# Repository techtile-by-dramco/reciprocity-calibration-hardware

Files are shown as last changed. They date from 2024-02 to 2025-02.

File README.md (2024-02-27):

# Techtile PLL board ✅

This PCB was developed by Guus Leenders from KU Leuven, in collaboration with DRAMCO, with assistance from Jarne Van Mulders. The board is utilized in a distributed antenna or **Radioweave** infrastructure and delivers a phase-synchronous RF output to the USRP by means of a PPS and 10MHz signal. 

❗❗ This board is specifically designed for the **USRP B210** by Ettus. ❗❗

The PPS and 10MHz signals (coming from the octoclocks CDA2990) are amplified using on board buffers and are connected to the
* PLL IC (MAX287x) ❗❗ **--> allowing for ∿ phase synchronisation ∿**
* the flat cable connector (given that the raspberry pi also has access to these signals) ❗
* the input SMA connectors of the USRPs intself ❗❗
  * ** 10 MHz --> ∿ frequency synchronisation ∿ for internal (RF) PLLs**
  * ** PPS --> ⏰ time synchronisation ⏰**

The board is controlled via I2C commands and features a flat cable input connected to the RPI HAT (developed by DRAMCO) to drive the PLL output. The most important registers are displayed below.

###  PLL board general settings ⚙️

|Register name| byte |
|--|--|
|REGISTER_SETTINGS_DEVICE_ID | 0x00 |
|REGISTER_SETTINGS_HARDWARE_VERSION | 0x01 |
|REGISTER_SETTINGS_FIRMWARE_VERSION | 0x02 |
|REGISTER_SETTINGS_SAVE_TO_EEPROM | 0x03 |
|REGISTER_SETTINGS_PLL_REFERENCE_CLOCK  | 0x04 |
|REGISTER_SETTINGS_PLL_REFERENCE_DIVIDER| 0x06 |
|REGISTER_SETTINGS_LED_MODE | 0x07 |
|REGISTER_SETTINGS_LED_BLINK_ON_TIME | 0x08 |
|REGISTER_SETTINGS_LED_BLINK_OFF_TIME | 0x09 |

###  PLL (MAX287x) settings ⚙️

|Register name| byte | Remarks |
|--|--|--|
|REGISTER_PLL_POWER | 0x10 | |
|REGISTER_PLL_FREQUENCY | 0x11 | 2 byte (uint16) |
|REGISTER_PLL_ENABLE_OUTPUT | 0x13 | |
|REGISTER_PLL_LOCK_DETECTED | 0x14 | Read only |
|REGISTER_PLL_MODE | 0x15 | Read only |

# Phase synchronisation in Techtile ToDo 📝
- Work further on python script to achieve phase-synchronised outputs with the B210 USRP. Validate and visualize the signals on the oscilloscope by using two separate setups consisting of RPI, USRP, PLL, PPS, and 10 MHz input.
- Current status ⏳ PENDING ⏳

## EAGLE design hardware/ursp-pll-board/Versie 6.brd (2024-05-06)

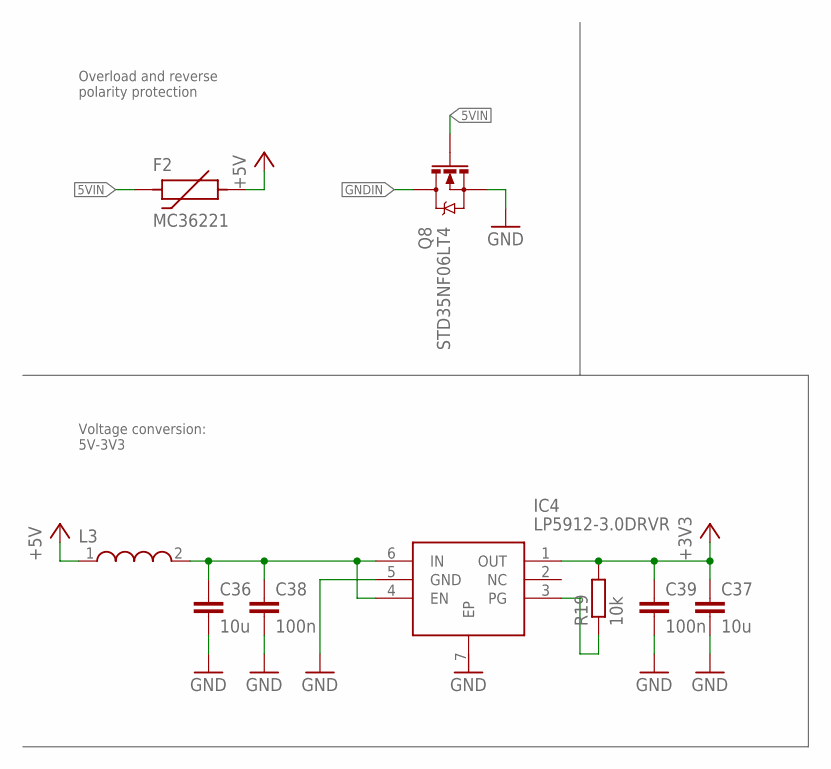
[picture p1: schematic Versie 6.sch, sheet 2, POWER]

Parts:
C36, C37: 10u; C0603
C38, C39: 100n; C0603
F2: MC36221; 1206
IC4: LP5912-3.0DRVR; SON65P200X200X80-7N
L3: WE-CBA_0603(WB/HS); WE-CBA_0603(W=2.2)
Q8: STD35NF06LT4; SOT23-3
R19: 10k; R0603

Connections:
5VIN: F2.P$1, Q8.1 (G); also elsewhere on the board
+3V3: C37.1, C39.1, IC4.1 (OUT), R19.2; also elsewhere on the board
+5V: F2.P$2, L3.1
GND: C36.2, C37.2, C38.2, C39.2, IC4.5 (GND), Q8.2 (S); also elsewhere on the board
GNDIN: Q8.3 (D); also elsewhere on the board
unnamed: C36.1, C38.1, IC4.4 (EN), IC4.6 (IN), L3.2
unnamed: IC4.3 (PG), R19.1

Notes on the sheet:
Overload and reverse polarity protection
Voltage conversion: 5V-3V3

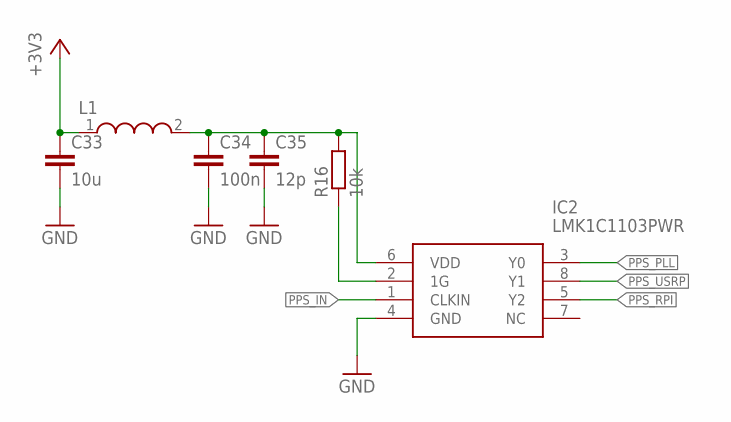
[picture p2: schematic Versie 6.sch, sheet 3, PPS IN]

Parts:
C33: 10u; C0603
C34: 100n; C0603
C35: 12p; C0603
IC2: LMK1C1103PWR; SOP65P640X120-8N
L1: WE-CBA_0603(WB/HS); WE-CBA_0603(W=2.2)
R16: 10k; R0603

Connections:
+3V3: C33.1, L1.1; also elsewhere on the board
GND: C33.2, C34.2, C35.2, IC2.4 (GND); also elsewhere on the board
unnamed: IC2.2 (1G), R16.1
unnamed: C34.1, C35.1, IC2.6 (VDD), L1.2, R16.2
PPS_IN: IC2.1 (CLKIN); also elsewhere on the board
PPS_PLL: IC2.3 (Y0); also elsewhere on the board
PPS_RPI: IC2.5 (Y2); also elsewhere on the board
PPS_USRP: IC2.8 (Y1); also elsewhere on the board

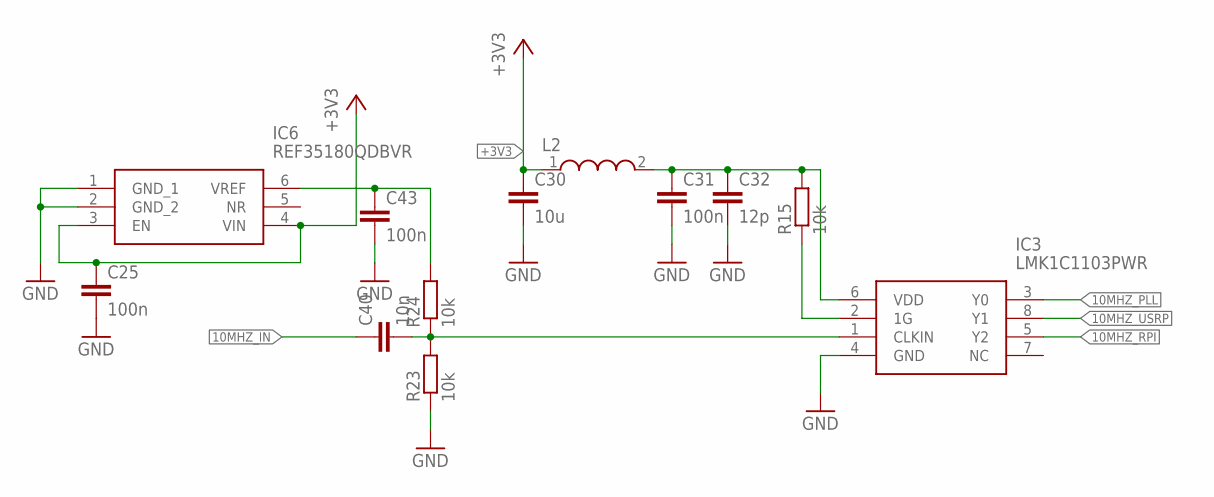
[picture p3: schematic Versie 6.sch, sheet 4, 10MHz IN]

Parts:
C25, C31, C43: 100n; C0603
C30: 10u; C0603
C32: 12p; C0603
C40: 10n; C0603
IC3: LMK1C1103PWR; SOP65P640X120-8N
IC6: REF35180QDBVR; SOT95P280X145-6N
L2: WE-CBA_0603(WB/HS); WE-CBA_0603(W=2.2)
R15, R23, R24: 10k; R0603

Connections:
10MHZ_IN: C40.1; also elsewhere on the board
10MHZ_PLL: IC3.3 (Y0); also elsewhere on the board
10MHZ_RPI: IC3.5 (Y2); also elsewhere on the board
10MHZ_USRP: IC3.8 (Y1); also elsewhere on the board
+3V3: C25.1, C30.1, IC6.3 (EN), IC6.4 (VIN), L2.1; also elsewhere on the board
GND: C25.2, C30.2, C31.2, C32.2, C43.2, IC3.4 (GND), IC6.1 (GND_1), IC6.2 (GND_2), R23.1; also elsewhere on the board
unnamed: C40.2, IC3.1 (CLKIN), R23.2, R24.1
unnamed: IC3.2 (1G), R15.1
unnamed: C31.1, C32.1, IC3.6 (VDD), L2.2, R15.2
unnamed: C43.1, IC6.6 (VREF), R24.2

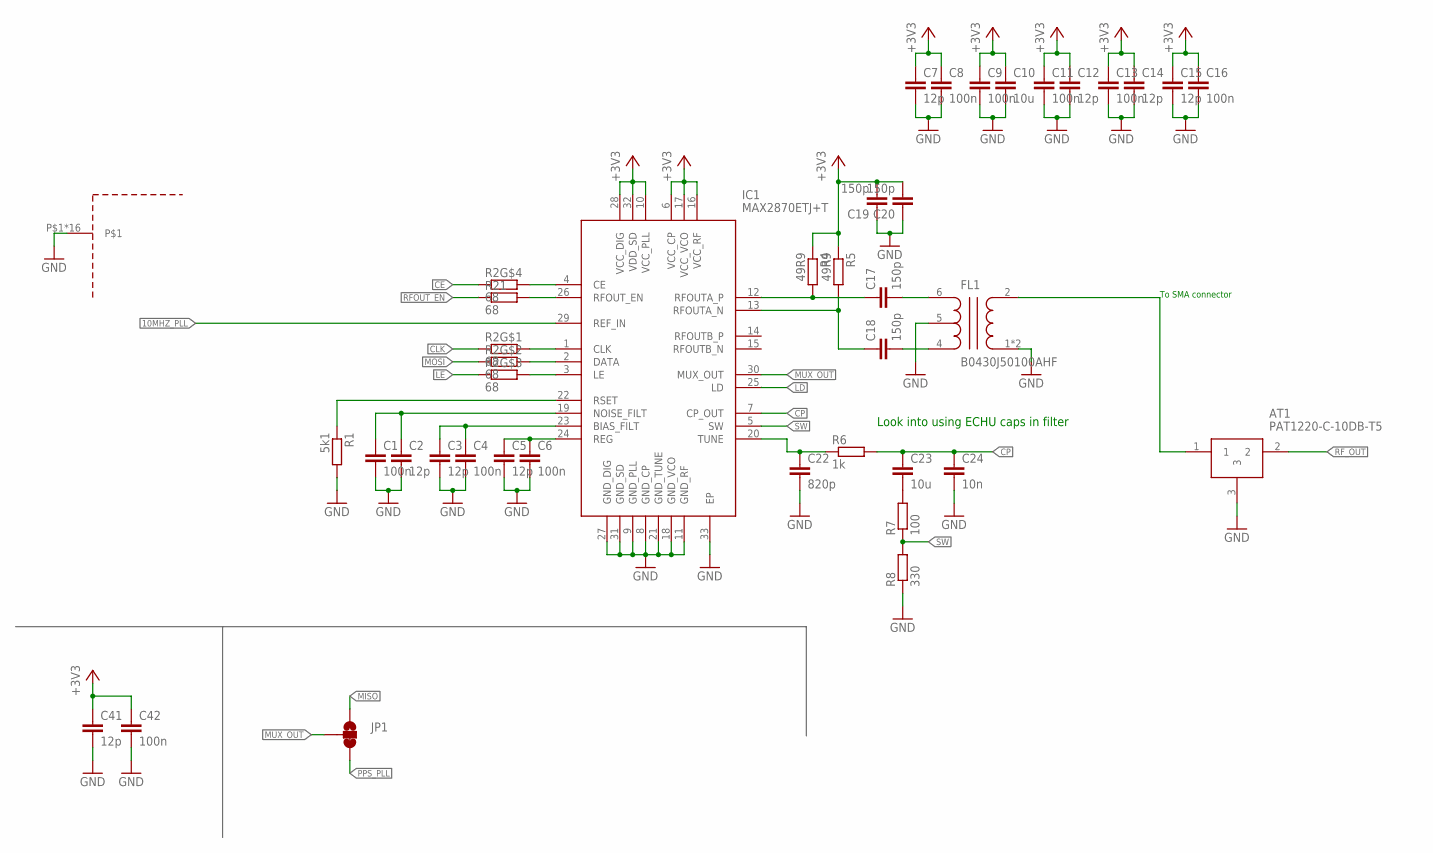
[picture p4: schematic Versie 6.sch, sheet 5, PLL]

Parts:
AT1: PAT1220-C-10DB-T5; PAT1220C10DBT5
C1, C4, C6, C8, C9, C11, C13, C16, C42: 100n; C0603
C2, C3, C5, C7, C12, C14, C15, C41: 12p; C0603
C10, C23: 10u; C0603
C17, C18, C19, C20: 150p; C0402
C22: 820p; C0603
C24: 10n; C0603
FL1: B0430J50100AHF
IC1: MAX2870ETJ+T; QFN50P500X500X80-33N
JP1: JUMPER-SMT_3_1-NC_TRACE_SILK; SMT-JUMPER_3_1-NC_TRACE_SILK
R1: 5k1; R0603
R2: 68; CAY16A1003F4LF
R4, R5: 49R9; R0402
R6: 1k; R0603
R7: 100; R0603
R8: 330; R0603
R21: 68; R0603
U$1: BMI-S-209-F-20-R

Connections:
10MHZ_PLL: IC1.29 (REF_IN); also elsewhere on the board
+3V3: C7.1, C8.1, C9.1, C10.1, C11.1, C12.1, C13.1, C14.1, C15.1, C16.1, C19.2, C20.2, C41.1, C42.1, IC1.6 (VCC_CP), IC1.10 (VCC_PLL), IC1.16 (VCC_RF), IC1.17 (VCC_VCO), IC1.28 (VCC_DIG), IC1.32 (VDD_SD), R4.1, R5.1; also elsewhere on the board
CE: R2.4 (1); also elsewhere on the board
CLK: R2.1; also elsewhere on the board
CP: C23.1, C24.1, IC1.7 (CP_OUT), R6.2
GND: AT1.3, C1.2, C2.2, C3.2, C4.2, C5.2, C6.2, C7.2, C8.2, C9.2, C10.2, C11.2, C12.2, C13.2, C14.2, C15.2, C16.2, C19.1, C20.1, C22.2, C24.2, C41.2, C42.2, FL1.1 (GND_1), FL1.3 (GND_1), FL1.5 (NC), IC1.8 (GND_CP), IC1.9 (GND_PLL), IC1.11 (GND_RF), IC1.18 (GND_VCO), IC1.21 (GND_TUNE), IC1.27 (GND_DIG), IC1.31 (GND_SD), IC1.33 (EP), R1.2, R8.1, U$1.P$1, U$1.P$2, U$1.P$3, U$1.P$4, U$1.P$5, U$1.P$6, U$1.P$7, U$1.P$8, U$1.P$9, U$1.P$10, U$1.P$11, U$1.P$12, U$1.P$13, U$1.P$14, U$1.P$15, U$1.P$16; also elsewhere on the board
LD: IC1.25 (LD); also elsewhere on the board
LE: R2.3 (1); also elsewhere on the board
MISO: JP1.1; also elsewhere on the board
MOSI: R2.2 (1); also elsewhere on the board
MUX_OUT: IC1.30 (MUX_OUT), JP1.2
unnamed: C5.1, C6.1, IC1.24 (REG)
unnamed: IC1.22 (RSET), R1.1
unnamed: IC1.1 (CLK), R2.8 (2)
unnamed: IC1.2 (DATA), R2.7 (2)
unnamed: IC1.3 (LE), R2.6 (2)
unnamed: C1.1, C2.1, IC1.19 (NOISE_FILT)
unnamed: C3.1, C4.1, IC1.23 (BIAS_FILT)
unnamed: IC1.26 (RFOUT_EN), R21.2
unnamed: IC1.4 (CE), R2.5 (2)
unnamed: C22.1, IC1.20 (TUNE), R6.1
unnamed: C17.1, IC1.12 (RFOUTA_P), R4.2
unnamed: C18.1, IC1.13 (RFOUTA_N), R5.2
unnamed: C18.2, FL1.4 (BALANCED_PORT_1)
unnamed: C17.2, FL1.6 (BALANCED_PORT_2)
unnamed: C23.2, R7.2
unnamed: AT1.1, FL1.2 (UNBALANCED)
PPS_PLL: JP1.3; also elsewhere on the board
RFOUT_EN: R21.1; also elsewhere on the board
RF_OUT: AT1.2; also elsewhere on the board
SW: IC1.5 (SW), R7.1, R8.2

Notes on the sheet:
To SMA connector
Look into using ECHU caps in filter

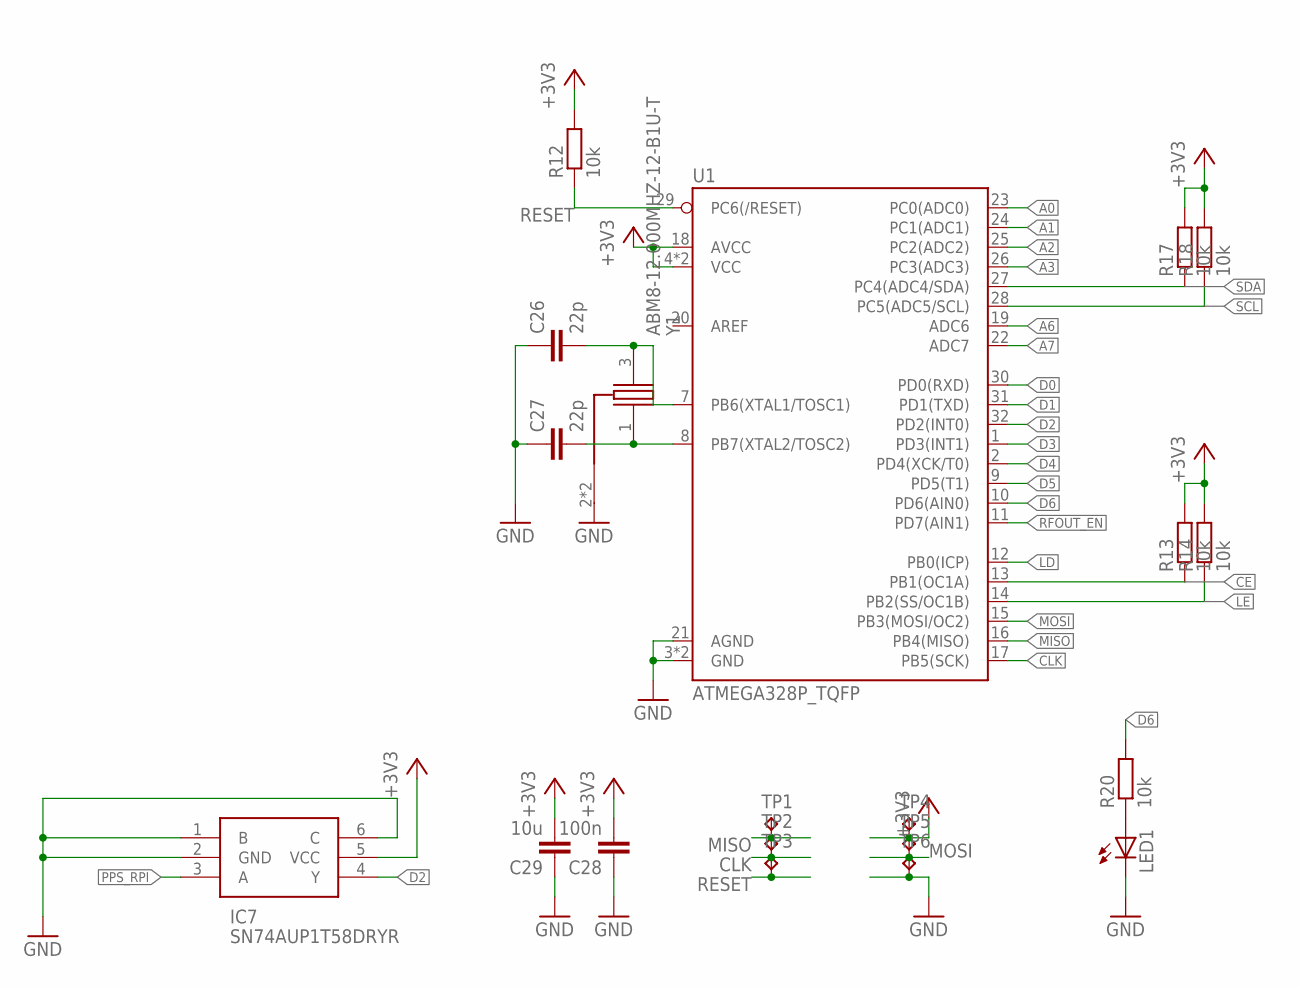
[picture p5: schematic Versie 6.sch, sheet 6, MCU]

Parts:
C26, C27: 22p; C0603
C28: 100n; C0603
C29: 10u; C0603
IC7: SN74AUP1T58DRYR; SON50P100X145X60-6N
LED1: LEDCHIPLED_0805; CHIPLED_0805
R12, R13, R14, R17, R18, R20: 10k; R0603
TP1, TP2, TP3, TP4, TP5, TP6: TPTP16R; TP16R
U1: ATMEGA328P_TQFP; TQFP32-08
Y1: ABM8-12.000MHZ-12-B1U-T; ABM810000MHZ12D2W

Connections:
+3V3: C28.2, C29.2, IC7.5 (VCC), R12.2, R13.2, R14.2, R17.2, R18.2, TP4.TP, U1.4 (VCC), U1.6 (VCC), U1.18 (AVCC); also elsewhere on the board
A0: U1.23 (PC0(ADC0)); also elsewhere on the board
A1: U1.24 (PC1(ADC1)); also elsewhere on the board
A2: U1.25 (PC2(ADC2)); also elsewhere on the board
A3: U1.26 (PC3(ADC3)); also elsewhere on the board
A6: U1.19 (ADC6)
A7: U1.22 (ADC7)
CE: R13.1, U1.13 (PB1(OC1A)); also elsewhere on the board
CLK: TP2.TP, U1.17 (PB5(SCK)); also elsewhere on the board
D0: U1.30 (PD0(RXD)); also elsewhere on the board
D1: U1.31 (PD1(TXD)); also elsewhere on the board
D2: IC7.4 (Y), U1.32 (PD2(INT0))
D3: U1.1 (PD3(INT1)); also elsewhere on the board
D4: U1.2 (PD4(XCK/T0)); also elsewhere on the board
D5: U1.9 (PD5(T1))
D6: R20.2, U1.10 (PD6(AIN0))
GND: C26.1, C27.1, C28.1, C29.1, IC7.1 (B), IC7.2 (GND), IC7.6 (C), LED1.C, TP6.TP, U1.3 (GND), U1.5 (GND), U1.21 (AGND), Y1.2 (GND_1), Y1.4 (GND_1); also elsewhere on the board
LD: U1.12 (PB0(ICP)); also elsewhere on the board
LE: R14.1, U1.14 (PB2(SS/OC1B)); also elsewhere on the board
MISO: TP1.TP, U1.16 (PB4(MISO)); also elsewhere on the board
MOSI: TP5.TP, U1.15 (PB3(MOSI/OC2)); also elsewhere on the board
unnamed: LED1.A, R20.1
unnamed: C26.2, U1.7 (PB6(XTAL1/TOSC1)), Y1.3 (X2)
unnamed: C27.2, U1.8 (PB7(XTAL2/TOSC2)), Y1.1 (X1)
PPS_RPI: IC7.3 (A); also elsewhere on the board
RESET: R12.1, TP3.TP, U1.29 (PC6(/RESET))
RFOUT_EN: U1.11 (PD7(AIN1)); also elsewhere on the board
SCL: R18.1, U1.28 (PC5(ADC5/SCL)); also elsewhere on the board
SDA: R17.1, U1.27 (PC4(ADC4/SDA)); also elsewhere on the board

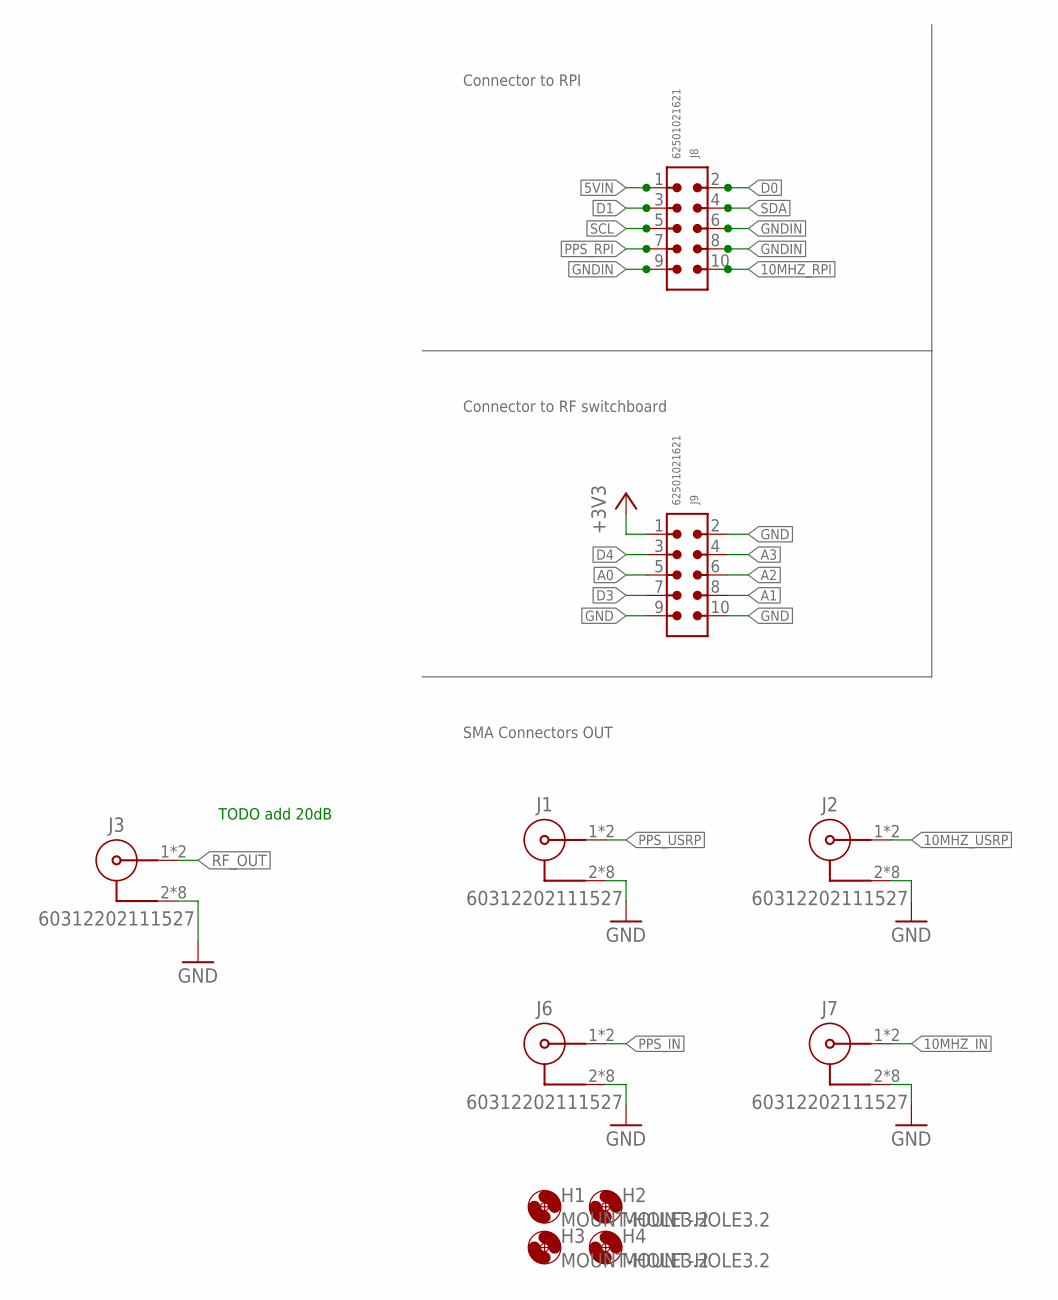
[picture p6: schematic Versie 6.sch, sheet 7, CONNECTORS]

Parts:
H1, H2, H3, H4: MOUNT-HOLE3.2; 3,2
J1, J2, J3, J6, J7: 60312202111527
J8, J9: 62501021621

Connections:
5VIN: J8.1; also elsewhere on the board
10MHZ_IN: J7.1, J7.6 (1); also elsewhere on the board
10MHZ_RPI: J8.10; also elsewhere on the board
10MHZ_USRP: J2.1, J2.6 (1); also elsewhere on the board
+3V3: J9.1; also elsewhere on the board
A0: J9.5; also elsewhere on the board
A1: J9.8; also elsewhere on the board
A2: J9.6; also elsewhere on the board
A3: J9.4; also elsewhere on the board
D0: J8.2; also elsewhere on the board
D1: J8.3; also elsewhere on the board
D3: J9.7; also elsewhere on the board
D4: J9.3; also elsewhere on the board
GND: J1.2, J1.3 (2), J1.4 (2), J1.5 (2), J1.7 (2), J1.8 (2), J1.9 (2), J1.10 (2), J2.2, J2.3 (2), J2.4 (2), J2.5 (2), J2.7 (2), J2.8 (2), J2.9 (2), J2.10 (2), J3.2, J3.3 (2), J3.4 (2), J3.5 (2), J3.7 (2), J3.8 (2), J3.9 (2), J3.10 (2), J6.2, J6.3 (2), J6.4 (2), J6.5 (2), J6.7 (2), J6.8 (2), J6.9 (2), J6.10 (2), J7.2, J7.3 (2), J7.4 (2), J7.5 (2), J7.7 (2), J7.8 (2), J7.9 (2), J7.10 (2), J9.2, J9.9, J9.10; also elsewhere on the board
GNDIN: J8.6, J8.8, J8.9; also elsewhere on the board
PPS_IN: J6.1, J6.6 (1); also elsewhere on the board
PPS_RPI: J8.7; also elsewhere on the board
PPS_USRP: J1.1, J1.6 (1); also elsewhere on the board
RF_OUT: J3.1, J3.6 (1); also elsewhere on the board
SCL: J8.5; also elsewhere on the board
SDA: J8.4; also elsewhere on the board

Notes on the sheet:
Connector to RPI
Connector to RF switchboard
SMA Connectors OUT
TODO add 20dB

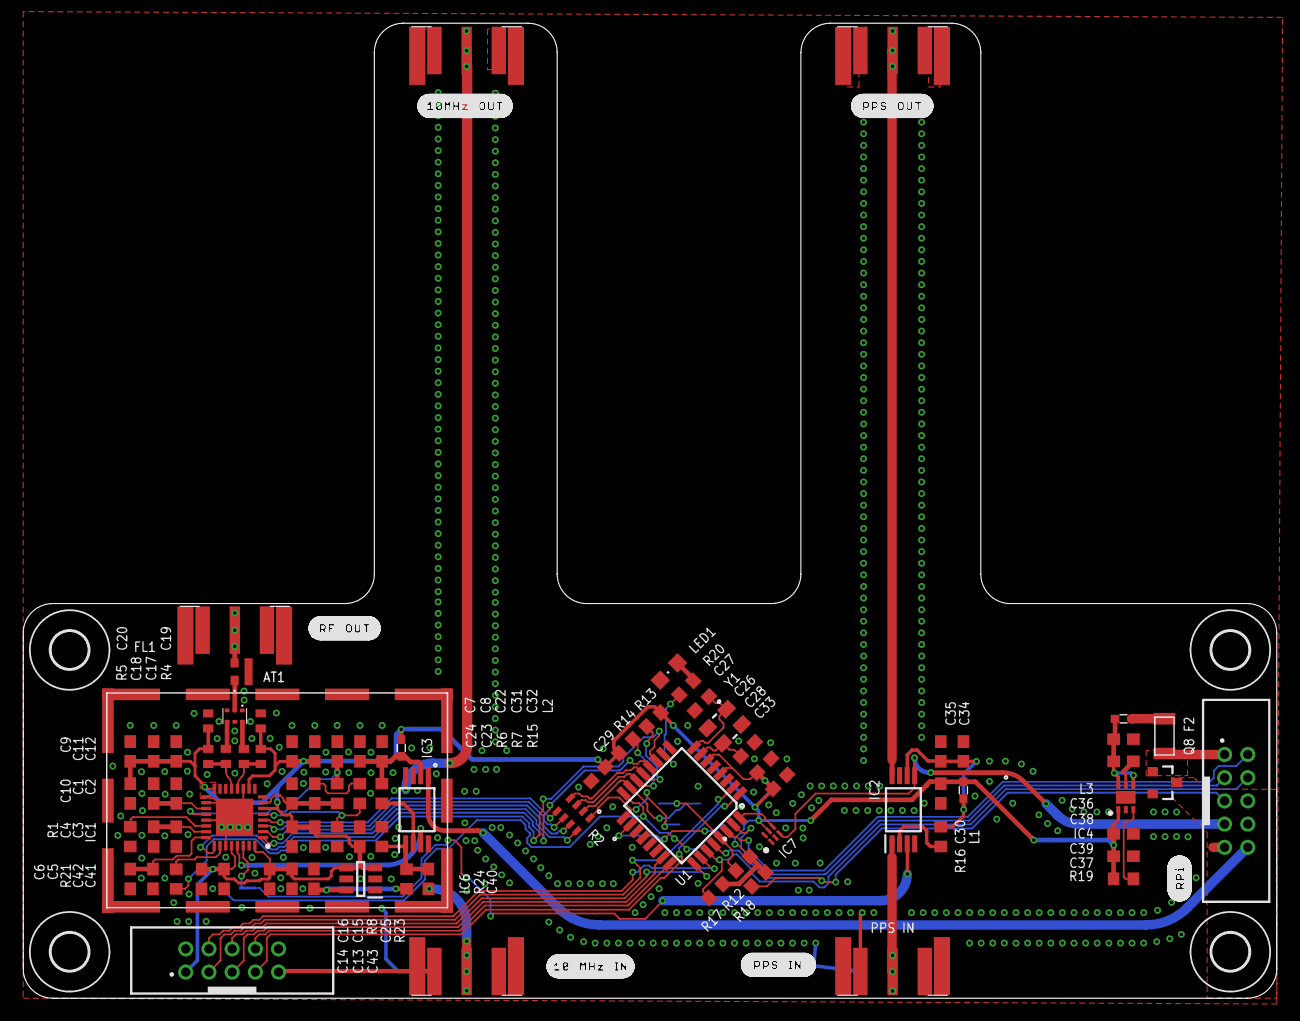
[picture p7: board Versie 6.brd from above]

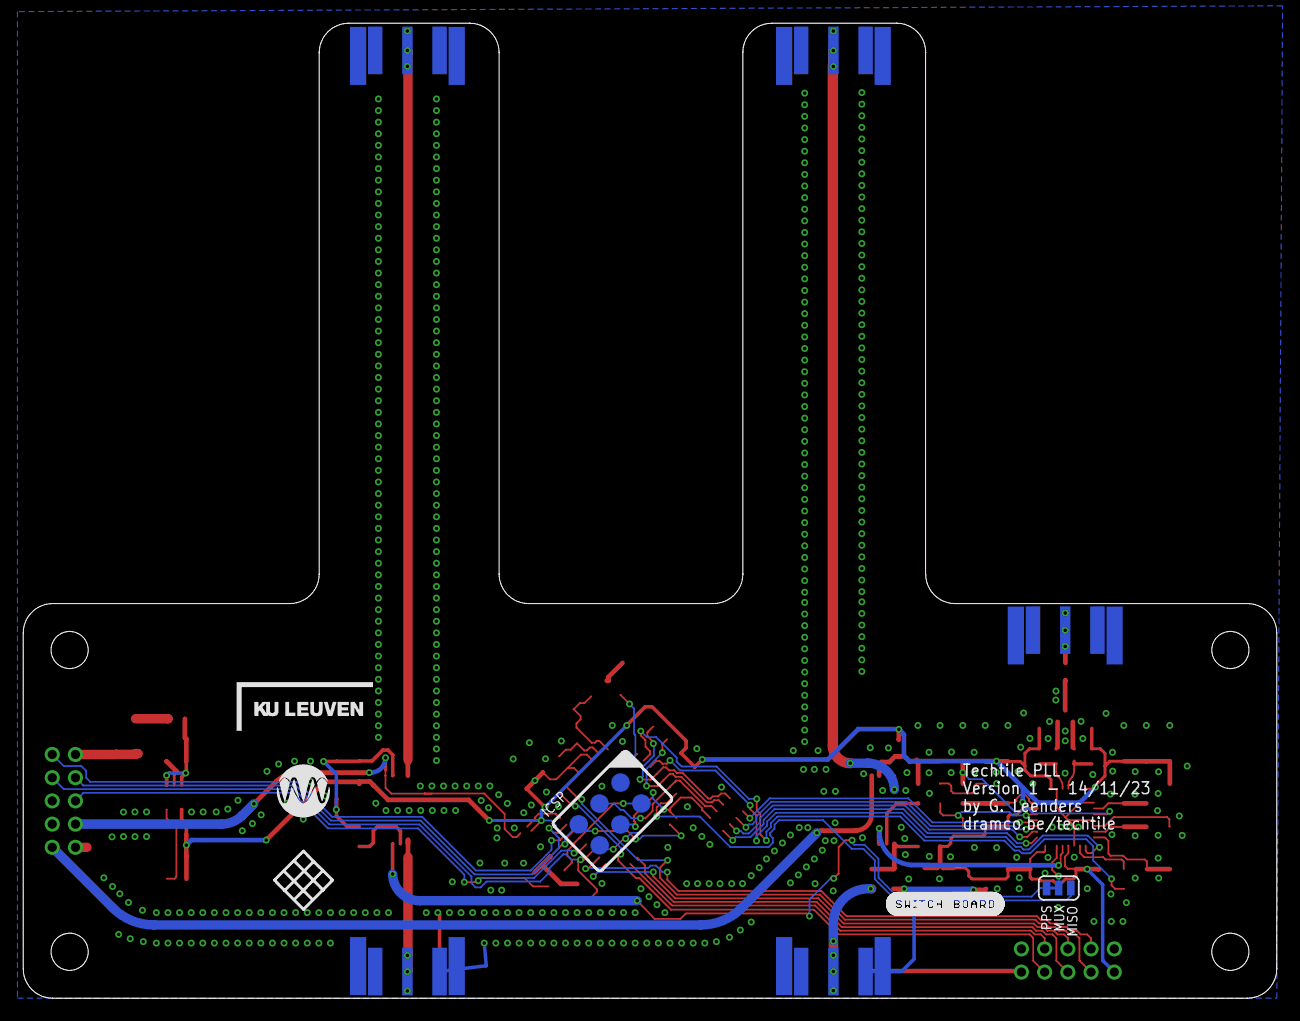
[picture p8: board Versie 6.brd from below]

Board: 2 copper layers, 108.0 x 84.0 mm, 96 parts (7 on the bottom side), 64 nets.

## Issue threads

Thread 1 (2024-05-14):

Remote I/O error

GillesC, 2024-05-14:
Error when running `python3 setup_PLL.py --freq 920`
```sh
Traceback (most recent call last):
  File "setup_PLL.py", line 39, in <module>
    main()
  File "setup_PLL.py", line 15, in main
    p = pll.PLL()
  File "/home/pi/reciprocity-calibration-hardware/software/pll.py", line 57, in __init__
    self._frequency = self.get_PLL_frequency()
  File "/home/pi/reciprocity-calibration-hardware/software/pll.py", line 106, in get_PLL_frequency
    return self._device.readU16(REGISTER_PLL_FREQUENCY)
  File "/home/pi/.local/lib/python3.7/site-packages/Adafruit_GPIO/I2C.py", line 164, in readU16
    result = self._bus.read_word_data(self._address,register) & 0xFFFF
  File "/usr/local/lib/python3.7/dist-packages/Adafruit_PureIO/smbus.py", line 226, in read_word_data
    ioctl(self._device.fileno(), I2C_RDWR, request)
OSError: [Errno 121] Remote I/O error
```

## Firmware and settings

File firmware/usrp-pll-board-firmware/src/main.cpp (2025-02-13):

#include <Arduino.h>
#include <nI2C.h>
#include <avr/wdt.h>
#include <EEPROM.h>

#include "MAX2871.h"
#include <SPI.h>

#define DEBUG

// -------- HARDWARE PINS -------------
#define MOSI        11
#define MISO        12
#define SCLK        13
#define LE          10
#define LD          8
#define RFOUTEN     7
#define CE          9 
#define LED         6
#define PPS         2
#define SWITCH1_V1  A6
#define SWITCH2_V1  A1
#define SWITCH2_V2  A2
#define SWITCH3_V1  A7
#define SWITCH3_V2  A3
#define SWITCH4_V1  A0

// -------- REGISTER BANK -------------
// 0x0?: SETTINGS
#define REGISTER_SETTINGS_DEVICE_ID             0x00
#define REGISTER_SETTINGS_HARDWARE_VERSION      0x01
#define REGISTER_SETTINGS_FIRMWARE_VERSION      0x02
#define REGISTER_SETTINGS_SAVE_TO_EEPROM        0x03
#define REGISTER_SETTINGS_PLL_REFERENCE_CLOCK   0x04 // 2 byte (uint16)
#define REGISTER_SETTINGS_PLL_REFERENCE_DIVIDER 0x06
#define REGISTER_SETTINGS_LED_MODE              0x07
#define REGISTER_SETTINGS_LED_BLINK_ON_TIME     0x08
#define REGISTER_SETTINGS_LED_BLINK_OFF_TIME    0x09
#define REGISTER_SETTINGS_PLL_REFERENCE_DOUBLER 0x0A

#define REGISTER_START_SETTINGS                 0x00
#define REGISTER_END_SETTINGS                   0x10

// 0x1?: PLL OPERATION
#define REGISTER_PLL_POWER                      0x10
#define REGISTER_PLL_FREQUENCY                  0x11 // 2 byte (uint16)
#define REGISTER_PLL_ENABLE_OUTPUT              0x13
#define REGISTER_PLL_LOCK_DETECTED              0x14 // Read only
#define REGISTER_PLL_MODE                       0x15 // Read only

// 0x2?: Switch board operation (GPIO control)
#define REGISTER_SWITCH1_VALUE                  0x20
#define REGISTER_SWITCH2_VALUE                  0x21
#define REGISTER_SWITCH3_VALUE                  0x22
#define REGISTER_SWITCH4_VALUE                  0x23

// Register bank settings
#define EEPROM_STATUS_ADDRESS                   0
#define EEPROM_START_ADDRESS                    1
#define REGISTER_RESPONSE_SIZE                  32

#define REGISTER_MAP_SIZE                       REGISTER_SWITCH4_VALUE+1
#define REGISTER_MAP_NR_READ_ONLY               2

// -------- VALUES CONSTANTS -----------
#define EEPROM_DISABLE                          0
#define EEPROM_SETTINGS                         1
#define EEPROM_ALL                              2

#define LED_MODE_OFF                            0
#define LED_MODE_ON                             1
#define LED_MODE_BLINK                          2
#define LED_MODE_PPS_BLINK                      3
#define LED_MODE_LOCK_DETECT                    4
#define LED_MODE_PPS_BLINK_AND_LOCK_DETECT      5

// Switch 1
#define SWITCH_RFATXRX_LOOP                     0
#define SWITCH_RFATXRX_OUT                      1
// Switch 2
#define SWITCH_SHUTDOWN                         0
#define SWITCH_RFARX2_RF                        1
#define SWITCH_RFARX2_LOOP                      2
#define SWITCH_RFARX2_OUT                       3
// Switch 3
// Also shutdown supported, same constant as 2
#define SWITCH_RFBRX2_RF                        1
#define SWITCH_RFBRX2_LOOP                      2
#define SWITCH_RFBRX2_OUT                       3
// Switch 4
#define SWITCH_RFBTXRX_LOOP                     0
#define SWITCH_RFBTXRX_OUT                      1


// -------- DEFAULT VALUES -----------
#define SETTINGS_DEVICE_ID                      0
#define SETTINGS_HARDWARE_VERSION               0
#define SETTINGS_FIRMWARE_VERSION               0
#define SETTINGS_SAVE_TO_EEPROM                 EEPROM_SETTINGS // 0: Don't save, 1: only save settigs, 2: save complete register map
#define SETTINGS_PLL_REFERENCE_CLOCK            (double) 10.0
#define SETTINGS_PLL_REFERENCE_DIVIDER          1
#define SETTINGS_LED_MODE                       LED_MODE_LOCK_DETECT // 0: Off, 1: On, 2: Blink, 3: PPS blink, 4: Lock detect, 5: Lock detect && PPS blink, PPS not implemented in V1
#define SETTINGS_LED_BLINK_ON_TIME              20 // *10 ms
#define SETTINGS_LED_BLINK_OFF_TIME             80 // *10 ms


#define DEFAULT_PLL_POWER                       1
#define DEFAULT_REGISTER_PLL_FREQUENCY_0        0x98 // Low byte 920 MHz default = 0x0398
#define DEFAULT_REGISTER_PLL_FREQUENCY_1        0x03 // High byte
#define DEFAULT_REGISTER_PLL_ENABLE_OUTPUT      1


// --------- DIRECT ACCESS TO PLL REGISTERS ---------
#define PLL_DIRECT_ACCESS_MASK                  0xF0

enum address_i2c_t : byte{
    ADDRESS_I2C = 0x2F // Address of I2C device
};

// Global I2C object
CTWI i2c;

// Register map vars
uint8_t readOnlyRegisters[] = {REGISTER_PLL_LOCK_DETECTED, REGISTER_PLL_MODE};
uint8_t registerMap[REGISTER_MAP_SIZE] = {0x00};
bool registerMapUpdate = true;
bool registerMapSettingsUpdate = true;
uint8_t lastRegister = 0;

volatile bool ppsHappened = false;
uint32_t lastLedTime = 0;
uint16_t ledTimeout = 0;

// Callback function prototype
void i2cWriteCallback(const uint8_t data[], const uint8_t length);
void i2cReadCallback(void);
void readEEPROM(void);
void updateEEPROM(void);
void ppsISR(void);

// PLL Object
MAX2871 max2871(LE, MOSI, SCLK, MISO);           //create object of class MAX2871, assign latch enable pin

void setup(){
  // --- Serial setup for debugging only
#ifdef DEBUG
  Serial.begin(9600);
#endif

  // --- Setup for I2C and register map ---
  i2c.SetLocalDeviceAddress(ADDRESS_I2C);
  
  // Set read and write callback
  i2c.SetSlaveReceiveHandler(i2cWriteCallback);
  i2c.SetSlaveTransmitHandler(i2cReadCallback);

  // Load config from EEPROM
  if(EEPROM.read(EEPROM_STATUS_ADDRESS) == 1){
    readEEPROM();
  }else{
    registerMap[REGISTER_SETTINGS_DEVICE_ID] = SETTINGS_DEVICE_ID;
    registerMap[REGISTER_SETTINGS_HARDWARE_VERSION] = SETTINGS_HARDWARE_VERSION;
    registerMap[REGISTER_SETTINGS_FIRMWARE_VERSION] = SETTINGS_FIRMWARE_VERSION;
    registerMap[REGISTER_SETTINGS_SAVE_TO_EEPROM] = SETTINGS_SAVE_TO_EEPROM;
    registerMap[REGISTER_SETTINGS_PLL_REFERENCE_CLOCK] = SETTINGS_PLL_REFERENCE_CLOCK;
    registerMap[REGISTER_SETTINGS_PLL_REFERENCE_DIVIDER] = SETTINGS_PLL_REFERENCE_DIVIDER;
    registerMap[REGISTER_SETTINGS_LED_MODE] = SETTINGS_LED_MODE;
    registerMap[REGISTER_SETTINGS_LED_BLINK_ON_TIME] = SETTINGS_LED_BLINK_ON_TIME;
    registerMap[REGISTER_SETTINGS_LED_BLINK_OFF_TIME] = SETTINGS_LED_BLINK_OFF_TIME;

    updateEEPROM();
  }

  // --- Setup for PLL ---
  // General IO setup
  pinMode(LE, OUTPUT);
  pinMode(LD, INPUT);
  pinMode(RFOUTEN, OUTPUT);
  pinMode(CE, OUTPUT);
  pinMode(MOSI, OUTPUT);
  pinMode(MISO, INPUT);
  pinMode(SCLK, OUTPUT);
  pinMode(LED, OUTPUT);
  pinMode(PPS, INPUT);

  attachInterrupt(digitalPinToInterrupt(PPS), ppsISR, RISING);

  digitalWrite(LE, HIGH);
  digitalWrite(LED, LOW);
  digitalWrite(RFOUTEN, HIGH);

  digitalWrite(CE, LOW);
  delay(100);
  digitalWrite(CE, HIGH);

  // Set default values
  registerMap[REGISTER_PLL_POWER] = DEFAULT_PLL_POWER;
  registerMap[REGISTER_PLL_FREQUENCY] = DEFAULT_REGISTER_PLL_FREQUENCY_0;
  registerMap[REGISTER_PLL_FREQUENCY+1] = DEFAULT_REGISTER_PLL_FREQUENCY_1;
  registerMap[REGISTER_PLL_ENABLE_OUTPUT] = DEFAULT_REGISTER_PLL_ENABLE_OUTPUT;

  max2871.begin();
  //max2871.powerOn(true);              //set all hardware enable pins and deassert software shutdown bits
  //max2871.setPFD(10.0,1);             //inputs are reference frequency and R divider to set phase/frequency detector comparison frequency

#ifdef DEBUG
  Serial.println("Setup done");
#endif
}

void loop(){
  
  wdt_reset();

  // LED functions
  if(millis() - lastLedTime > ledTimeout || ppsHappened){
    if(ppsHappened){
#ifdef DEBUG
      Serial.println("PPS happened");
#endif
    }else{
#ifdef DEBUG
      Serial.print(".");
#endif
    }
    if(!digitalRead(LED)){ // LED is off, turn it on if we have to
      digitalWrite(LED, registerMap[REGISTER_SETTINGS_LED_MODE] == LED_MODE_ON || registerMap[REGISTER_SETTINGS_LED_MODE] == LED_MODE_BLINK || (ppsHappened && registerMap[REGISTER_SETTINGS_LED_MODE] == LED_MODE_PPS_BLINK) || (registerMap[REGISTER_SETTINGS_LED_MODE] == LED_MODE_LOCK_DETECT && digitalRead(LD)) || (ppsHappened && registerMap[REGISTER_SETTINGS_LED_MODE] == LED_MODE_PPS_BLINK_AND_LOCK_DETECT && digitalRead(LD)));
      ledTimeout = registerMap[REGISTER_SETTINGS_LED_BLINK_ON_TIME]*10;
    }else{ // LED is on, turn it off if a blink setting is selected
      digitalWrite(LED, !(registerMap[REGISTER_SETTINGS_LED_MODE] == LED_MODE_OFF || registerMap[REGISTER_SETTINGS_LED_MODE] == LED_MODE_BLINK || registerMap[REGISTER_SETTINGS_LED_MODE] == LED_MODE_PPS_BLINK || (registerMap[REGISTER_SETTINGS_LED_MODE] == LED_MODE_LOCK_DETECT && !digitalRead(LD)) || registerMap[REGISTER_SETTINGS_LED_MODE] == LED_MODE_PPS_BLINK_AND_LOCK_DETECT));
      ledTimeout = registerMap[REGISTER_SETTINGS_LED_BLINK_OFF_TIME]*10;
    }
    lastLedTime = millis();

    ppsHappened = false;
  }

  // Settings updated
  if(registerMapSettingsUpdate){
    updateEEPROM();
    uint16_t frequency = (uint16_t) ( registerMap[REGISTER_SETTINGS_PLL_REFERENCE_CLOCK] | (uint16_t)registerMap[REGISTER_SETTINGS_PLL_REFERENCE_CLOCK+1]<<8 );
    max2871.setPFD(frequency, registerMap[REGISTER_SETTINGS_PLL_REFERENCE_DIVIDER], registerMap[REGISTER_SETTINGS_PLL_REFERENCE_DOUBLER]);
#ifdef DEBUG
    Serial.print("c:");
    Serial.println(frequency);
    Serial.print("d:");
    Serial.println(registerMap[REGISTER_SETTINGS_PLL_REFERENCE_DIVIDER]);
#endif

    registerMapSettingsUpdate = false;
  }

  // Function registers updated
  if(registerMapUpdate){
    if(registerMap[REGISTER_SETTINGS_SAVE_TO_EEPROM] == EEPROM_ALL)
      updateEEPROM();

    if(registerMap[REGISTER_PLL_POWER] > 0){
      max2871.powerOn(true); 
    }else{
      max2871.powerOn(false);
    }

    // Repeat this, to be on the save side
    uint16_t frequency = (uint16_t) ( registerMap[REGISTER_SETTINGS_PLL_REFERENCE_CLOCK] | (uint16_t)registerMap[REGISTER_SETTINGS_PLL_REFERENCE_CLOCK+1]<<8 );
    max2871.setPFD(frequency, registerMap[REGISTER_SETTINGS_PLL_REFERENCE_DIVIDER], registerMap[REGISTER_SETTINGS_PLL_REFERENCE_DOUBLER]);

    frequency = (uint16_t) ( registerMap[REGISTER_PLL_FREQUENCY] | (uint16_t)registerMap[REGISTER_PLL_FREQUENCY+1]<<8 );
    if((frequency < 100) && (frequency > 6000)){ 
#ifdef DEBUG
        Serial.println("\n\rNot a valid frequency entry."); 
        Serial.println(frequency) ;
#endif
    }else{
      max2871.setRFOUTA((double) frequency);

      if(registerMap[REGISTER_PLL_ENABLE_OUTPUT] > 0){
        max2871.enable_output();
      }else{
        max2871.disable_output();
      }
    }

    // Switch 1
    digitalWrite(SWITCH1_V1, registerMap[REGISTER_SWITCH1_VALUE]);
    // Switch 2
    digitalWrite(SWITCH2_V1, bitRead(registerMap[REGISTER_SWITCH2_VALUE], 1));
    digitalWrite(SWITCH2_V2, bitRead(registerMap[REGISTER_SWITCH2_VALUE], 0));
    // Switch 3
    digitalWrite(SWITCH3_V1, bitRead(registerMap[REGISTER_SWITCH3_VALUE], 1));
    digitalWrite(SWITCH3_V2, bitRead(registerMap[REGISTER_SWITCH3_VALUE], 0));
    // Switch 1
    digitalWrite(SWITCH4_V1, registerMap[REGISTER_SWITCH4_VALUE]);

    registerMapUpdate = false;
  }

  // Set readonly registers
  registerMap[REGISTER_PLL_MODE] = max2871.getMode();
  registerMap[REGISTER_PLL_LOCK_DETECTED] = digitalRead(LD);

}

void readEEPROM(){
#ifdef DEBUG
  Serial.println("E0");
#endif

  // First read settings in temp buffer
  uint8_t registerMapTemp[REGISTER_END_SETTINGS] = {0x00};
  for(uint8_t reg = REGISTER_START_SETTINGS; reg < REGISTER_END_SETTINGS; reg++){
    registerMapTemp[reg] = EEPROM.read(reg - REGISTER_START_SETTINGS + EEPROM_START_ADDRESS);
  }

  // Now read everything according to new settings
  if(registerMapTemp[REGISTER_SETTINGS_SAVE_TO_EEPROM] != EEPROM_DISABLE){
    uint8_t end = REGISTER_END_SETTINGS;
    if(registerMapTemp[REGISTER_SETTINGS_SAVE_TO_EEPROM] == EEPROM_ALL)
      end = REGISTER_MAP_SIZE;
    for(uint8_t reg = REGISTER_START_SETTINGS; reg < end; reg++){
      registerMap[reg] = EEPROM.read(reg - REGISTER_START_SETTINGS + EEPROM_START_ADDRESS);
    }
  }
}

void updateEEPROM(){
#ifdef DEBUG
  Serial.println("E1");
#endif

  EEPROM.update(EEPROM_STATUS_ADDRESS, 1);

  if(registerMap[REGISTER_SETTINGS_SAVE_TO_EEPROM] != EEPROM_DISABLE){
    uint8_t end = REGISTER_END_SETTINGS;
    if(registerMap[REGISTER_SETTINGS_SAVE_TO_EEPROM] == EEPROM_ALL)
      end = REGISTER_MAP_SIZE;
    for(uint8_t reg = REGISTER_START_SETTINGS; reg < end; reg++){
      EEPROM.update(reg - REGISTER_START_SETTINGS + EEPROM_START_ADDRESS, registerMap[reg]);
    }
  }
}

void i2cWriteCallback(const uint8_t data[], const uint8_t length){
#ifdef DEBUG
  Serial.println("I2C write");
#endif

  if(data[0] < REGISTER_MAP_SIZE){
    // Buffer this register so we can answer to a read request later
    lastRegister = data[0];

    // If more bytes are transferred: write operation
    if(length > 1){

      // Buffer the readonly regs that can be in between
      uint8_t readOnlyTemp[REGISTER_MAP_NR_READ_ONLY];
      for(uint8_t i = 0; i < REGISTER_MAP_NR_READ_ONLY; i++){
        readOnlyTemp[i] = registerMap[readOnlyRegisters[i]];
      }
      // Copy new data
      memcpy(&registerMap[lastRegister], &data[1], length-1);
      // Put readonly back
      for(uint8_t i = 0; i < REGISTER_MAP_NR_READ_ONLY; i++){
        registerMap[readOnlyRegisters[i]] = readOnlyTemp[i];
      }
      registerMapUpdate = true;
      // Refresh EEPROM when we wrote things to settings registers
      if(lastRegister < REGISTER_END_SETTINGS || lastRegister + length < REGISTER_END_SETTINGS ){
        registerMapSettingsUpdate = true;
      }
    }
  }else if(data[0] & PLL_DIRECT_ACCESS_MASK == PLL_DIRECT_ACCESS_MASK){
    if(length > 1){
      for(uint8_t i = 1; i < length; i++){
        max2871.setRegister(data[0]& ~PLL_DIRECT_ACCESS_MASK, data[i]);
      }
    }
  }
}

void i2cReadCallback(void){
  // Send message to master
#ifdef DEBUG
  Serial.println("I2C read");
#endif

  if(lastRegister & PLL_DIRECT_ACCESS_MASK == PLL_DIRECT_ACCESS_MASK){
    uint8_t pllRegister = lastRegister & ~PLL_DIRECT_ACCESS_MASK;
    uint8_t buffer[7] = {0};
    max2871.getAll(buffer, 7);
    i2c.SlaveQueueNonBlocking(buffer+pllRegister, 7-pllRegister);
  }else{
    uint8_t size = REGISTER_RESPONSE_SIZE; 
    if(lastRegister + REGISTER_RESPONSE_SIZE > REGISTER_MAP_SIZE){
      size = REGISTER_MAP_SIZE - lastRegister;
    } 

    i2c.SlaveQueueNonBlocking(registerMap + lastRegister, size);
  }
}

void ppsISR(void){
  ppsHappened = true;
}

int find(uint8_t a[], uint8_t size, uint8_t item){
    int i, pos = -1;
    for (i = 0; i < size; i++) {
        if (a[i] == item) {
            pos = i;
            break;
        }
    }
    return pos;
}

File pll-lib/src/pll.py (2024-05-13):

import time
import struct

# Default address of PLL board
PLL_ADDRESS                             = 0x2F
# -------- REGISTER BANK -------------
# 0x0?: SETTINGS
REGISTER_SETTINGS_DEVICE_ID             = 0x00
REGISTER_SETTINGS_HARDWARE_VERSION      = 0x01
REGISTER_SETTINGS_FIRMWARE_VERSION      = 0x02
REGISTER_SETTINGS_SAVE_TO_EEPROM        = 0x03
REGISTER_SETTINGS_PLL_REFERENCE_CLOCK   = 0x04 # 2 byte (uint16)
REGISTER_SETTINGS_PLL_REFERENCE_DIVIDER = 0x06
REGISTER_SETTINGS_LED_MODE              = 0x07
REGISTER_SETTINGS_LED_BLINK_ON_TIME     = 0x08
REGISTER_SETTINGS_LED_BLINK_OFF_TIME    = 0x09

REGISTER_START_SETTINGS                 = 0x00
REGISTER_END_SETTINGS                   = 0x10

# 0x1?: PLL OPERATION
REGISTER_PLL_POWER                      = 0x10
REGISTER_PLL_FREQUENCY                  = 0x11 # 2 byte (uint16)
REGISTER_PLL_ENABLE_OUTPUT              = 0x13
REGISTER_PLL_LOCK_DETECTED              = 0x14 # Read only
REGISTER_PLL_MODE                       = 0x15 # Read only

REGISTER_MAP_SIZE                       = REGISTER_PLL_MODE+1
REGISTER_MAP_NR_READ_ONLY               = 2

# Register bank settings
EEPROM_STATUS_ADDRESS                   = 0
EEPROM_START_ADDRESS                    = 1
REGISTER_RESPONSE_SIZE                  = 32

# -------- VALUES CONSTANTS -----------
EEPROM_DISABLE                          = 0
EEPROM_SETTINGS                         = 1
EEPROM_ALL                              = 2

LED_MODE_OFF                            = 0
LED_MODE_ON                             = 1
LED_MODE_BLINK                          = 2
LED_MODE_PPS_BLINK                      = 3
LED_MODE_LOCK_DETECT                    = 4
LED_MODE_PPS_BLINK_AND_LOCK_DETECT      = 5

class PLL(object):
    def __init__(self, address=PLL_ADDRESS, i2c=None, **kwargs):
        if i2c is None:
            import Adafruit_GPIO.I2C as I2C
            i2c = I2C
        self._device = i2c.get_i2c_device(address, **kwargs)

        self.output = self.get_PLL_enable_output()
        self.power = self.get_PLL_power()
        self._frequency = self.get_PLL_frequency()

        self.divider = self.get_PLL_reference_divider()
        self.reference_clock = self.get_PLL_reference_clock()

    # ---- Settings -----
    # - Getters
    def get_PLL_reference_clock(self):
        result = self._device.readList(REGISTER_SETTINGS_PLL_REFERENCE_CLOCK, 4)
        return struct.unpack('f', result)[0]

    def get_PLL_reference_divider(self):
        return self._device.readU8(REGISTER_SETTINGS_PLL_REFERENCE_DIVIDER)
        
    def get_LED_mode(self):
        return self._device.readU8(REGISTER_SETTINGS_LED_MODE)

    def get_LED_blink_on_time(self):
        return self._device.readU8(REGISTER_SETTINGS_LED_BLINK_ON_TIME)*10

    def get_LED_blink_off_time(self):
        return self._device.readU8(REGISTER_SETTINGS_LED_BLINK_OFF_TIME)*10

    # - Setters
    def set_PLL_reference_clock(self, v):
        self._device.write16(REGISTER_SETTINGS_PLL_REFERENCE_CLOCK, v)
        self.reference_clock = v
        time.sleep(0.1)

    def set_PLL_reference_divider(self, v):
        self._device.write8(REGISTER_SETTINGS_PLL_REFERENCE_DIVIDER, v)
        self.divider = v
        time.sleep(0.1)

    def set_LED_mode(self, v):
        self._device.write8(REGISTER_SETTINGS_LED_MODE, v)

    def set_LED_blink_on_time(self, v):
        self._device.write8(REGISTER_SETTINGS_LED_BLINK_ON_TIME, v//10)

    def set_LED_blink_off_time(self, v):
        self._device.write8(REGISTER_SETTINGS_LED_BLINK_OFF_TIME, v//10)

    # ---- Operating instructions ----
    # - Getters
    def get_PLL_power(self):
        return self._device.readU8(REGISTER_PLL_POWER)

    def get_PLL_frequency(self):
        return self._device.readU16(REGISTER_PLL_FREQUENCY)

    def get_PLL_enable_output(self):
        return self._device.readU8(REGISTER_PLL_ENABLE_OUTPUT)

    def get_PLL_lock_detected(self):
        return self._device.readU8(REGISTER_PLL_LOCK_DETECTED)

    def get_PLL_mode(self):
        return self._device.readU8(REGISTER_PLL_MODE)

    # - Setters
    def set_PLL_power(self, v):
        self._device.write8(REGISTER_PLL_POWER, v)
        self.power = v
        time.sleep(0.1)

    def set_PLL_frequency(self, v):
        self._device.write16(REGISTER_PLL_FREQUENCY, v)
        self._frequency = v
        time.sleep(0.1)

    def set_PLL_enable_output(self, v):
        self._device.write8(REGISTER_PLL_ENABLE_OUTPUT, v)
        self.output = v
        time.sleep(0.1)

    # - Simpler naming functions

    def power_on(self):
        self.set_PLL_power(1)

    def power_off(self):
        self.set_PLL_power(0)

    def enable_output(self):
        self.set_PLL_enable_output(1)

    def disable_output(self):
        self.set_PLL_enable_output(0)

    def frequency(self, v:int):
        self.set_PLL_frequency(v)

    def locked(self):
        return self.get_PLL_lock_detected() > 0

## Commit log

2024-03-19 Added switch board firmware
2024-04-05 Redesigned board and expanded firmware
    [Versie 4.GBL, Versie 4.GBO, Versie 4.GBP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]
2024-04-05 Changed values of loop filter
    [Versie 5.brd, Versie 5.sch]
2024-05-06 Bug fixes
    [Versie 6.brd, Versie 6.sch]
2024-05-13 fixed duplicate name of method and attribute frequency
    [pll.py]

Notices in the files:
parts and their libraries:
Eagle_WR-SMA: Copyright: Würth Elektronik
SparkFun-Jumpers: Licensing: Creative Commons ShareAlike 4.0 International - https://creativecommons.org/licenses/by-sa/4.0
